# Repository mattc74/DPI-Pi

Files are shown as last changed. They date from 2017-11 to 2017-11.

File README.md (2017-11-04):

# DPI-Pi
18Bit DPI &amp; Back Light Driver for Raspi

This is a Small PCB Design aiming at using a parallel RGB 3.5" screen directly from the ras-pi GPIO Pins

The Screen used is: Model No. LQ035NC111 320x240 3.5" and is popular in GameBoy Projects.

Ammendments will need to be made to /boot/config.txt on the pi.

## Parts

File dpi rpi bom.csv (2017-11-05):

Qty | Value | Device | Package | Parts | Description
1 |  | PINHD-2X20 | 2X20 | JP1 | PIN HEADER
1 | 0.1uF | CAP_CERAMIC_0805MP | _0805MP | C38 | Ceramic Capacitors
1 | 10K | RESISTOR_0805MP | _0805MP | R38 | Resistors
1 | 10uF | CAP_CERAMIC_0805MP | _0805MP | C26 | Ceramic Capacitors
1 | 18Ω | RESISTOR_0805MP | _0805MP | R39 | Resistors
2 | 1uF | CAP_CERAMIC_0805MP | _0805MP | C37, C55 | Ceramic Capacitors
1 | 51296-5494 | 51296-5494 | 51296 | U$5 | Molex 0.5mm Pitch, Bottom contacts, 54 positions
1 | 6.8uH power L CID 2276 | INDUCTORNR5040 | INDUCTOR_5X5MM_NR5040_NOTHERMALS | L3 | Inductors
1 | FAN5333BSX | FAN5331 | SOT23-5@1 | U3 | FAN5331 - LED/OLED 20V Boost Converter
1 | MBR0540 | DIODESOD-123 | SOD-123 | D2 | Diode
1 | SZMM5Z24VT1G | DIODESMA | SMADIODE | D1 | Diode

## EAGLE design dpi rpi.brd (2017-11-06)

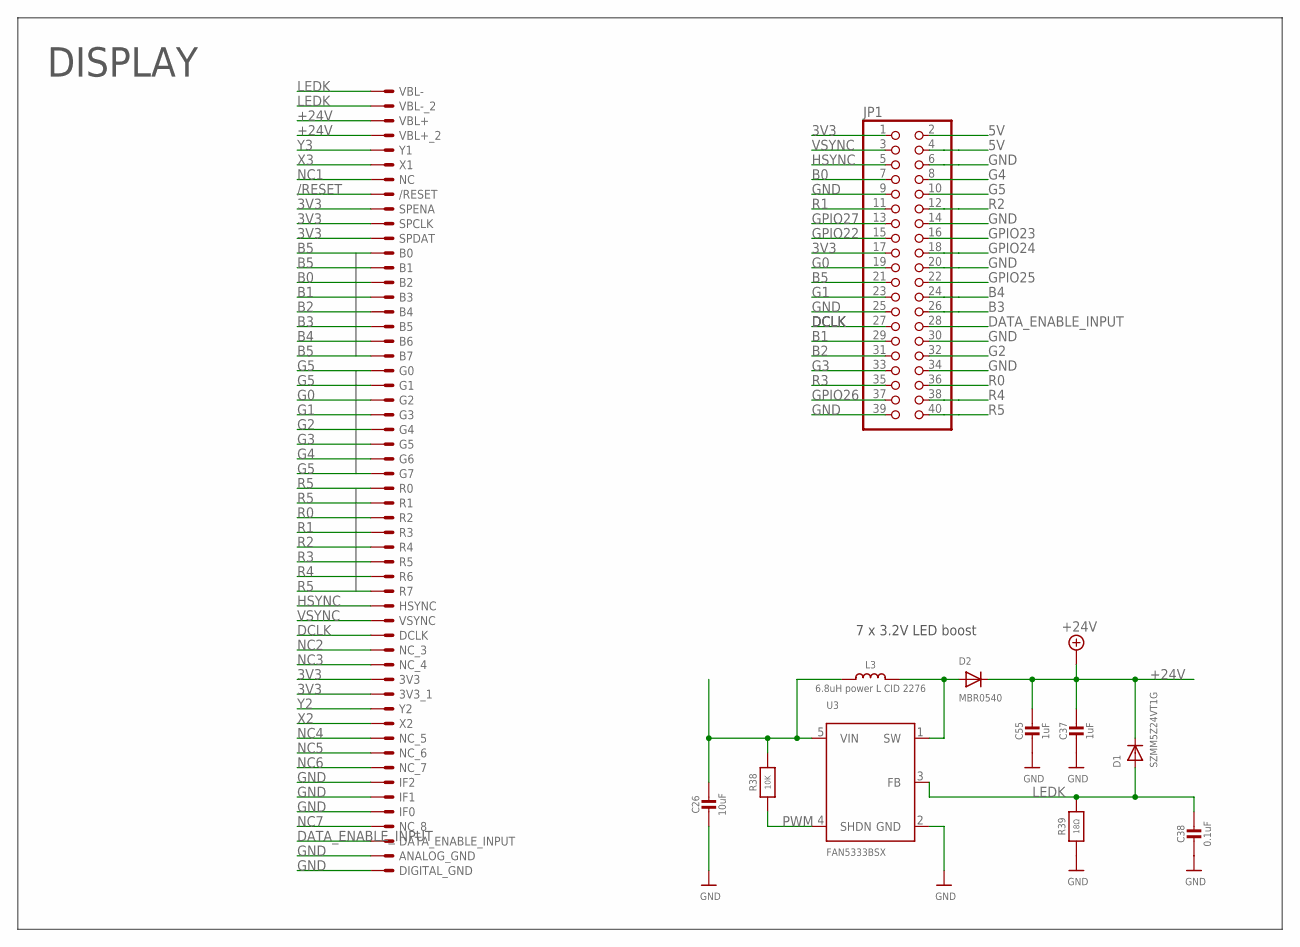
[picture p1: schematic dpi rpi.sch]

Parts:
C26: 10uF; _0805MP
C37, C55: 1uF; _0805MP
C38: 0.1uF; _0805MP
D1: SZMM5Z24VT1G; SMADIODE
D2: MBR0540; SOD-123
JP1: PINHD-2X20; 2X20
L3: 6.8uH power L CID 2276; INDUCTOR_5X5MM_NR5040_NOTHERMALS
R38: 10K; _0805MP
R39: 18Ω; _0805MP
U3: FAN5333BSX; SOT23-5@1
U$5: 51296-5494; 51296

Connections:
3V3: C26.1, JP1.1, JP1.17, L3.P$1 (1), R38.2, U3.5 (VIN), U$5.9 (SPENA), U$5.10 (SPCLK), U$5.11 (SPDAT), U$5.41 (3V3), U$5.42 (3V3_1)
5V: JP1.2, JP1.4
+24V: C37.1, C55.1, D1.C, D2.C, U$5.3 (VBL+), U$5.4 (VBL+_2)
/RESET: U$5.8 (/RESET)
B0: JP1.7, U$5.14 (B2)
B1: JP1.29, U$5.15 (B3)
B2: JP1.31, U$5.16 (B4)
B3: JP1.26, U$5.17 (B5)
B4: JP1.24, U$5.18 (B6)
B5: JP1.21, U$5.12 (B0), U$5.13 (B1), U$5.19 (B7)
DATA_ENABLE_INPUT: JP1.28, U$5.52 (DATA_ENABLE_INPUT)
DCLK: JP1.27, U$5.38 (DCLK)
G0: JP1.19, U$5.22 (G2)
G1: JP1.23, U$5.23 (G3)
G2: JP1.32, U$5.24 (G4)
G3: JP1.33, U$5.25 (G5)
G4: JP1.8, U$5.26 (G6)
G5: JP1.10, U$5.20 (G0), U$5.21 (G1), U$5.27 (G7)
GND: C26.2, C37.2, C38.2, C55.2, JP1.6, JP1.9, JP1.14, JP1.20, JP1.25, JP1.30, JP1.34, JP1.39, R39.1, U3.2 (GND), U$5.48 (IF2), U$5.49 (IF1), U$5.50 (IF0), U$5.53 (ANALOG_GND), U$5.54 (DIGITAL_GND)
GPIO22: JP1.15
GPIO23: JP1.16
GPIO24: JP1.18
GPIO25: JP1.22
GPIO26: JP1.37
GPIO27: JP1.13
HSYNC: JP1.5, U$5.36 (HSYNC)
LEDK: C38.1, D1.A, R39.2, U3.3 (FB), U$5.1 (VBL-), U$5.2 (VBL-_2)
unnamed: D2.A, L3.P$2 (2), U3.1 (SW)
NC1: U$5.7 (NC)
NC2: U$5.39 (NC_3)
NC3: U$5.40 (NC_4)
NC4: U$5.45 (NC_5)
NC5: U$5.46 (NC_6)
NC6: U$5.47 (NC_7)
NC7: U$5.51 (NC_8)
PWM: R38.1, U3.4 (SHDN)
R0: JP1.36, U$5.30 (R2)
R1: JP1.11, U$5.31 (R3)
R2: JP1.12, U$5.32 (R4)
R3: JP1.35, U$5.33 (R5)
R4: JP1.38, U$5.34 (R6)
R5: JP1.40, U$5.28 (R0), U$5.29 (R1), U$5.35 (R7)
VSYNC: JP1.3, U$5.37 (VSYNC)
X2: U$5.44 (X2)
X3: U$5.6 (X1)
Y2: U$5.43 (Y2)
Y3: U$5.5 (Y1)

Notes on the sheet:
DISPLAY
7 x 3.2V LED boost

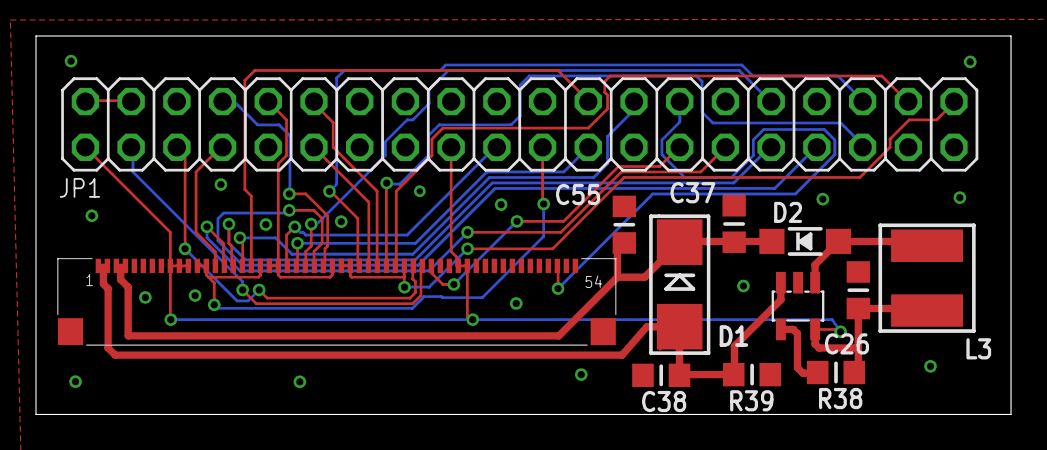
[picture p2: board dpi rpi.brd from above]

Board: 2 copper layers, 54.2 x 21.0 mm, 12 parts (0 on the bottom side), 29 nets.

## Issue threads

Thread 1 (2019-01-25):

Inductor

rodocop1985, 2019-01-25:
Hey there. Looking to build one of these. The inductor part number doesn't seem to match with anything on arrow or digikey. Do you have a link to the one you used? Or more information on it so I can select the right one?

Helder1981, 2019-01-25:
NR5040T6R8M is the perfect fit for this footprint:

https://www.digikey.com/products/en/inductors-coils-chokes/fixed-inductors/71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

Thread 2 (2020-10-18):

Artifacts when viewing higher color depth content

DoomyDoomer, 2020-10-18:
I'm noticing some odd imperfections in the image on screen that look like color drop outs or artifacts. I'm only noticing this in EmulationStation, RetroArch menus, and some PS1 games (usually during FMVs). All other content looks great and I don't see these artifacts.

**Things I've tried**
First, I double checked to make sure the config file matched your supplied file and it does. Next, I double checked for continuity between the 54 pin connector and the GPIO, PWR, or GND they were connected to with no issues. Then I inspected the 54 pin connector under a scope to make sure there were no solder bridges I may have missed the first. No bridges or other solder related issues. Finally, to rule out any sort of hardware issue, I built a second DPI board and it exhibits the same exact issue.

**Color depth artifacts**
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

**Sonic 2 looking great**
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

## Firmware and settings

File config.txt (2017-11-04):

#Lines required to enable 18bit DPI for use with Matts Pi-DPI

dtoverlay=dpi18
overscan_left=0
overscan_right=0
overscan_top=0
overscan_bottom=0
enable_dpi_lcd=1
display_default_lcd=1
dpi_group=2
dpi_mode=87

framebuffer_width=320
framebuffer_height=240
display_rotate=2
dpi_output_format=24597 #rgb
hdmi_timings=320 1 20 30 38 240 1 4 3 10 0 0 0 60 0 9600000 1
